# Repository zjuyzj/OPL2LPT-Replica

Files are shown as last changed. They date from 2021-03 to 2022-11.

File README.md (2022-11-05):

# OPL2LPT-Replica

## Introduction
**OPL2LPT-Replica** is a re-designed, open-source simplified version of OPL2LPT circuit board with fewer components under MIT license, acting as a YM3812 FM synthesizer on LPT port, and fully ***Adlib Card*** compatible.

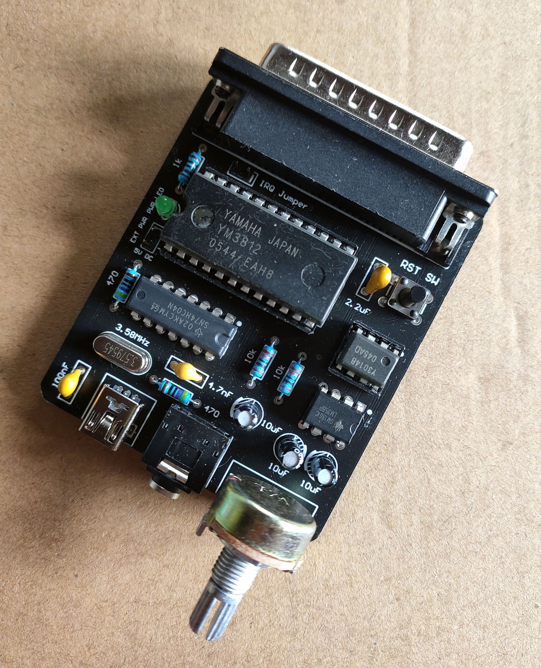
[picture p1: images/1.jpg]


Buy the original version of OPL2LPT and for more info: https://www.serdashop.com/OPL2LPT

## Development & Manufacture
- Please use ***Altium Designer 16*** or above to open or edit the PCB project

- Gerber files and NC drill files are already exported in `gerbers` folder, so that PCB samples can be easily manufactured

   https://www.jlc.com/ is recommended to order PCB samples in China

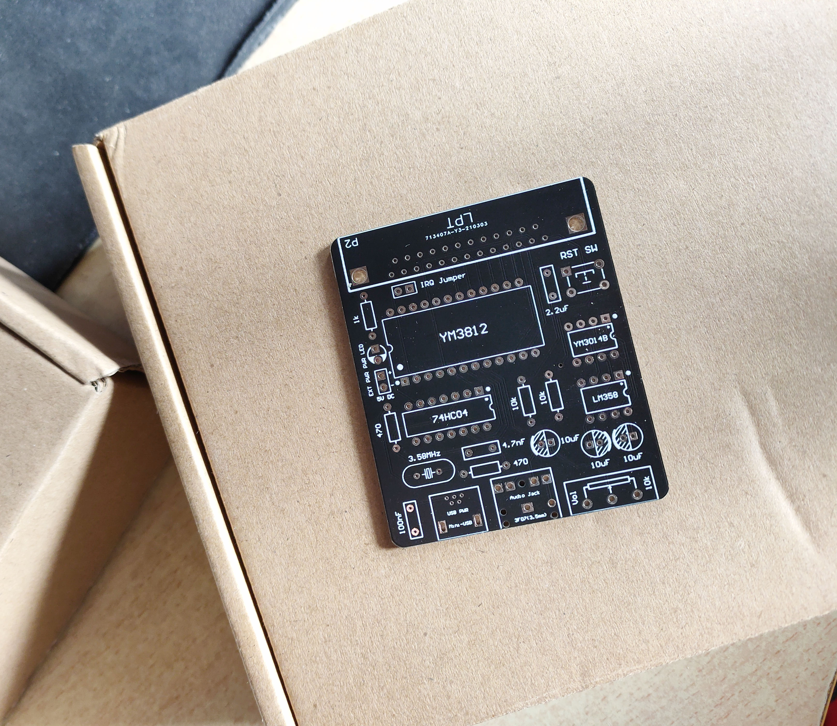
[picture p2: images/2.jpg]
   
## Bill of Material

| Component | Designator | Quantity | Note & Possible Sources |
| --- | --- | --- | --- |
| Leaded 100pF (101) MLCC | C1 | 1 | Mouser 594-K101J15C0GF5UH5 |
| Leaded 100nF (104) MLCC | C2 | 1 | Mouser 594-K104K15X7RF5UL2 |
| Leaded 10uF Pol. Cap. | C3, C5, C6 | 3 | Mouser 667-ECA-1EM100 |
| Leaded 2.2uF (225) MLCC | C4 | 1 | Mouser 81-RDER71H225K2M1H3A |
| Leaded 3mm Green LED | D1 | 1 | Mouser 630-HLMP-Y801-JPP00 |
| 74HC04 CMOS Inverters | IC1 | 1 | Mouser 595-CD74HC04E |
| Yamaha YM3014B DAC | IC2 | 1 | https://www.aliexpress.com/item/32611185781.html, DIP-8 socket is recommended |
| Yamaha YM3812 OPL2 | IC3 | 1 | https://www.aliexpress.com/item/32595976031.html, DIP-24 socket is recommended |
| LM358 Dual OP Amp | IC4 | 1 | Mouser 595-LM358AP |
| Leaded Mini USB Type B Connector | P1 | 1 | Mouser 571-2172034-1 |
| D-Sub 25P R/A Male Connector | P2 | 1 | Mouser 523-L717SDB25P1ACH3R |
| Header 2P 2.54mm | P3, W1 | 2 | Mouser 855-M20-9990246 |
| 3F07 3.5mm Stereo Audio Jack | P4 | 1 | https://www.aliexpress.com/i/32478957056.html |
| 1k 1/4W Resistor | R1, R2, R3 | 3 | Mouser 279-YR1B1K0CC |
| 10k WH148  Potentiometer | R4 | 1 | https://www.aliexpress.com/item/32998649900.html |
| 10k 1/4W Resistor | R5, R6 | 2 | Mouser 279-YR1B10KCC |
| TSW DIP-6\*6\*11 Key | S1 | 1 | https://www.aliexpress.com/item/32725384168.html |
| Crystal HC-49S 3.58MHz | Y1 | 1 | Mouser 449-LFXTAL032257BULK |

## Notes for Assembling & Testing
- 5V DC power is needed, either from Mini-USB port or external power pins

- Try to press **RST SW** to apply a manual reset when YM3812 behaves abnormal

- Detailed parameters for components are noted on the board's silkscreen

- Crystal must be 3.58MHz for accurate pitch of notes

- Using 74LS04 to substitute 74HC04 for the Pierce oscillator is not recommended

  **Note**: If the oscillator doesn't work, replace the two 1k ohms resistors around the 74HC04 IC with higher value resistors such as 4.7k ohms. Fine tuning for 100pF (101) MLCC capacitor around the 74HC04 may be also needed.

- Available open-source drivers for this project:
  - on MS-DOS: https://github.com/pdewacht/adlipt
    
    working fine using either method below
    
    - Using TSR  `adlipt`  for port mapping (with emm386.exe)
    - Using  `adpatch`  to patch part of DOS games
    
  - on Windows 3.1: https://github.com/andreiw/adlib21
## Update Logs
- Version 0.1(beta): First PCB for debugging
- Version 0.2(beta):
  - A smaller re-designed PCB
  - Audio quality improved
- Version 0.3(beta): Fix unconnected GND net for 3.5mm audio jack
- Version 1.0:
  - First version updated on https://github.com/
  - Fix power LED & volume control's problem
  - Use a round PCB corner for easier assembling (with a 3D-Printed case)
  - Pull-up resistors on bus are removed to improve compatibility for some old PCs
  - Use non-SMT Mini-USB port, making it easier to solder by hand
  - Add external 5V-DC power pins
- Version 1.0.1:
  - Add 3D-Printed case (with cover) and knob
  
    Thanks for **@zhblue** for your awesome *.stl models
  
  - Change directory structure for GitHub repo

- Version 1.1.0:
  - Fix clock problem caused by unsuitable resistors and capacitor for Pierce oscillator
  - Add Bill of Material and some images for this README document
  - Export PDF version for schematic and PCB documents

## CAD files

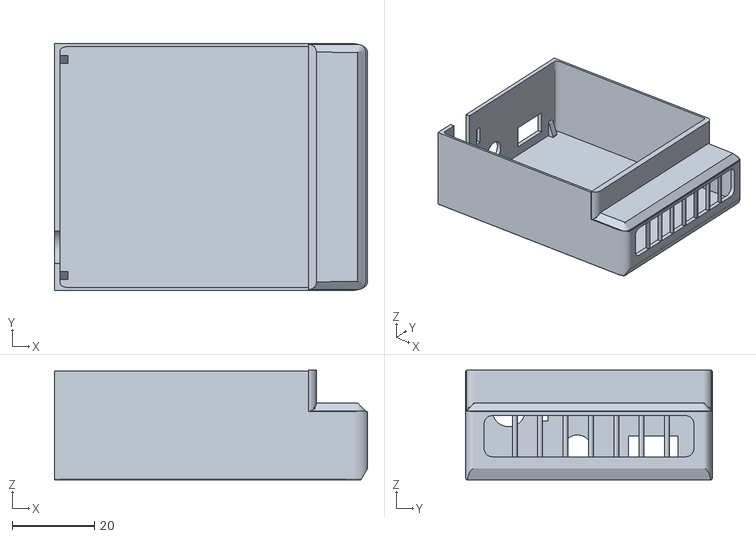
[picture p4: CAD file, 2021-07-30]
models/opl2box.stl
76.1 x 60.0 x 26.7

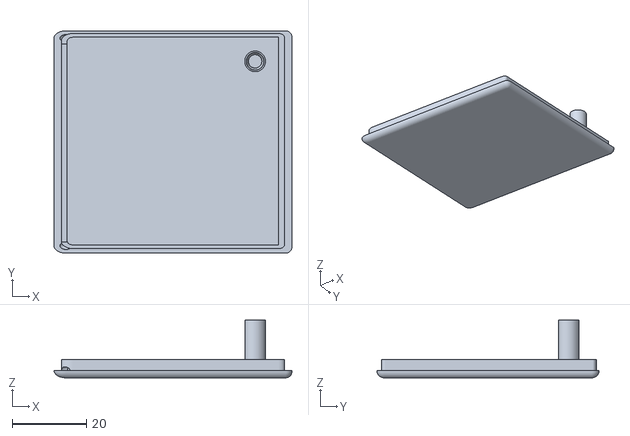
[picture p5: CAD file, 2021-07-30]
models/opl2cover.stl
64.2 x 60.0 x 15.6

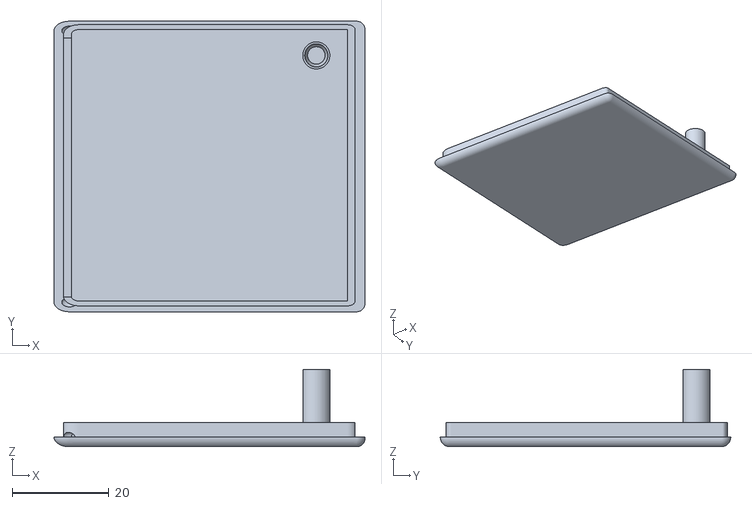
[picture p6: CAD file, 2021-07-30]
models/opl2coverb.stl
64.2 x 60.0 x 16.0

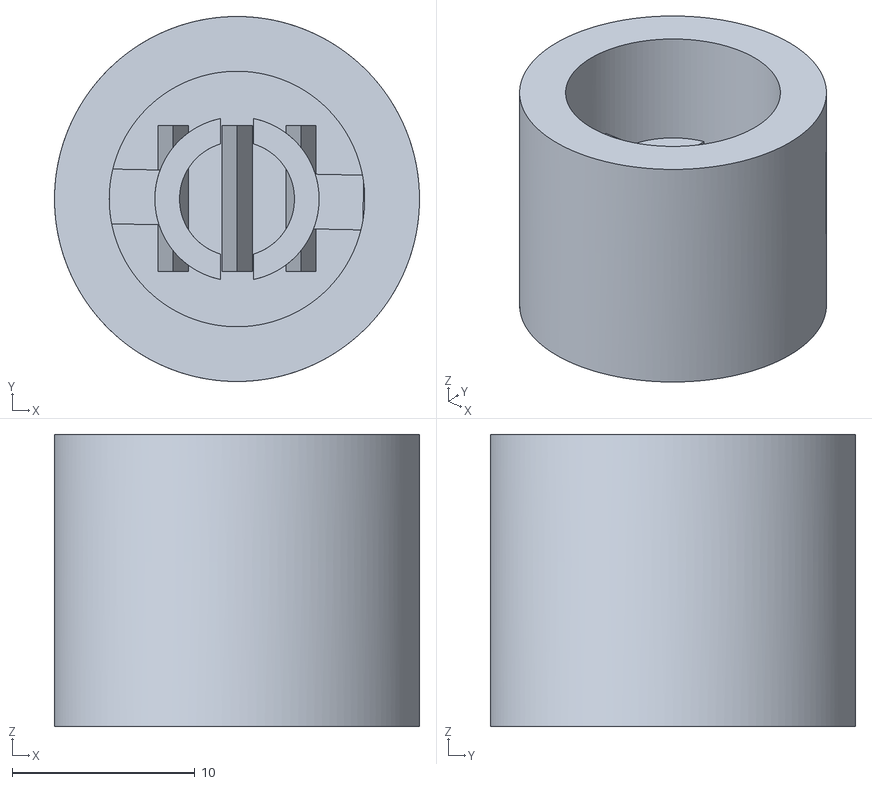
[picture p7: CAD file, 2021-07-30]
models/opl2knob.stl
20.0 x 20.0 x 16.0

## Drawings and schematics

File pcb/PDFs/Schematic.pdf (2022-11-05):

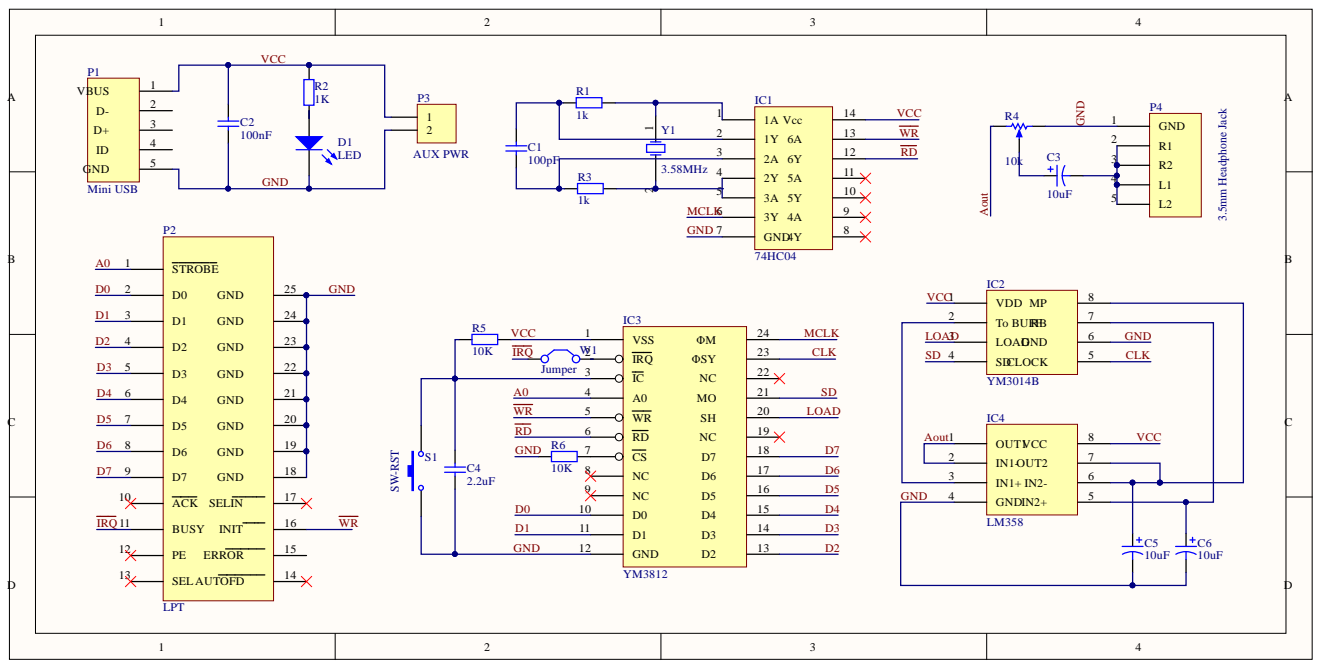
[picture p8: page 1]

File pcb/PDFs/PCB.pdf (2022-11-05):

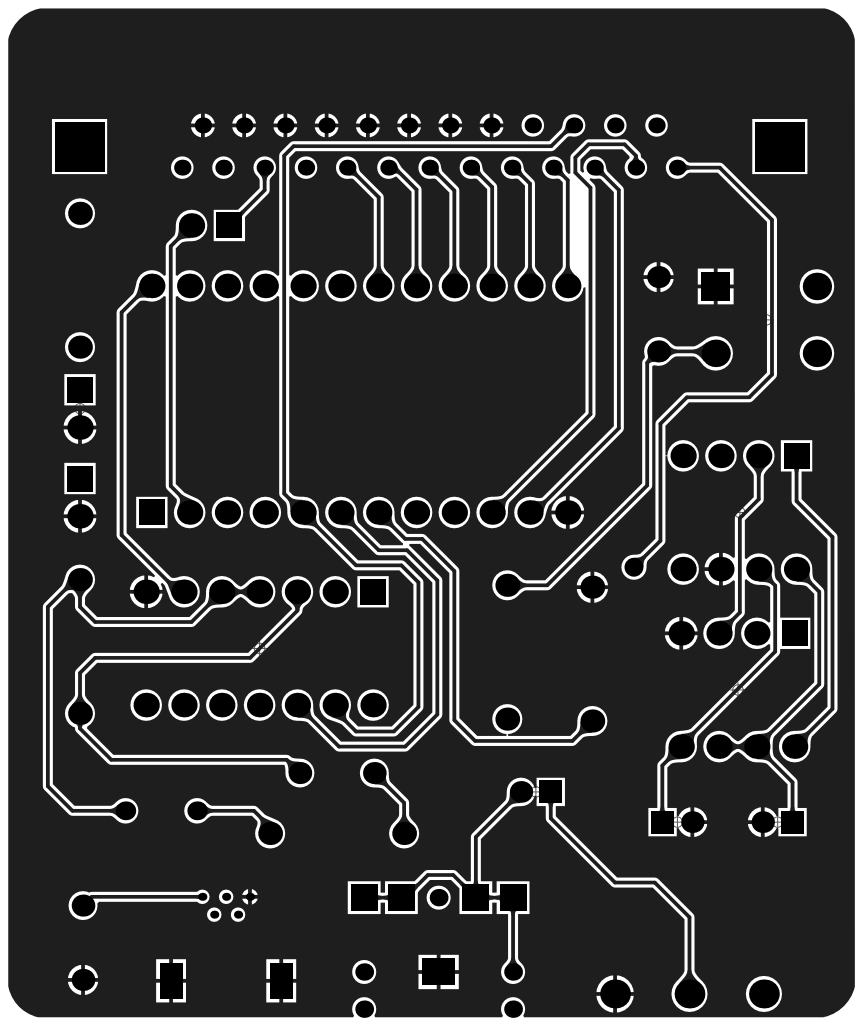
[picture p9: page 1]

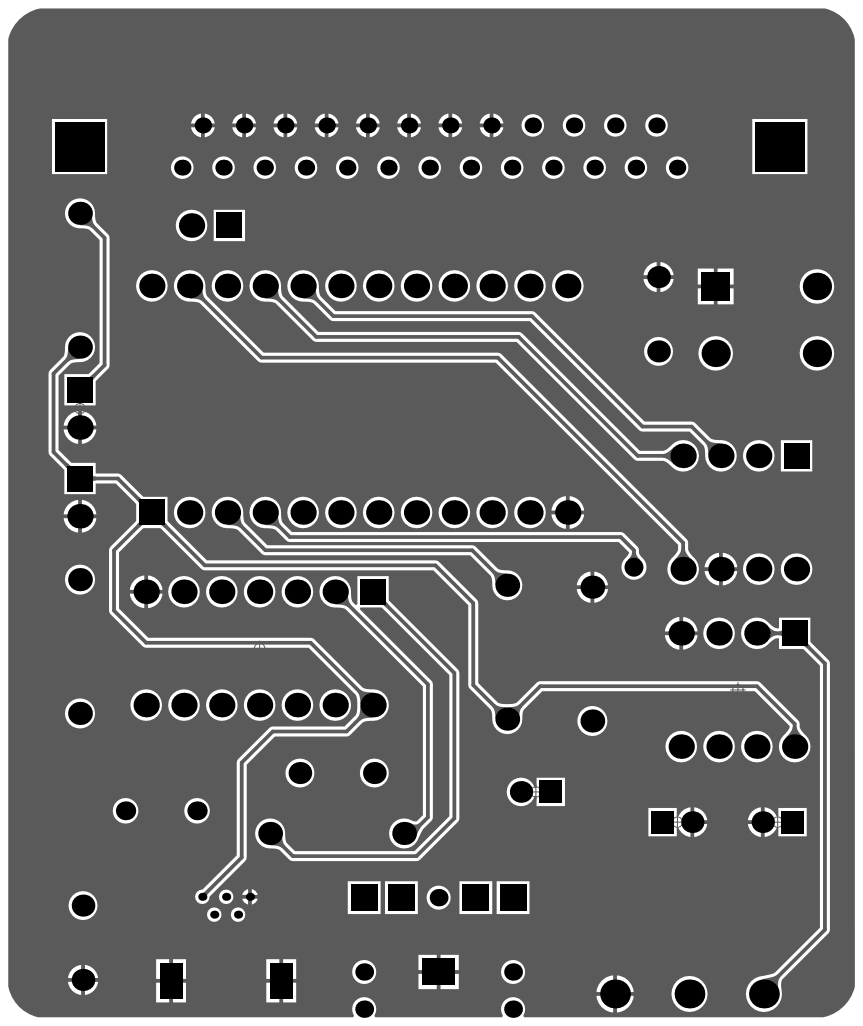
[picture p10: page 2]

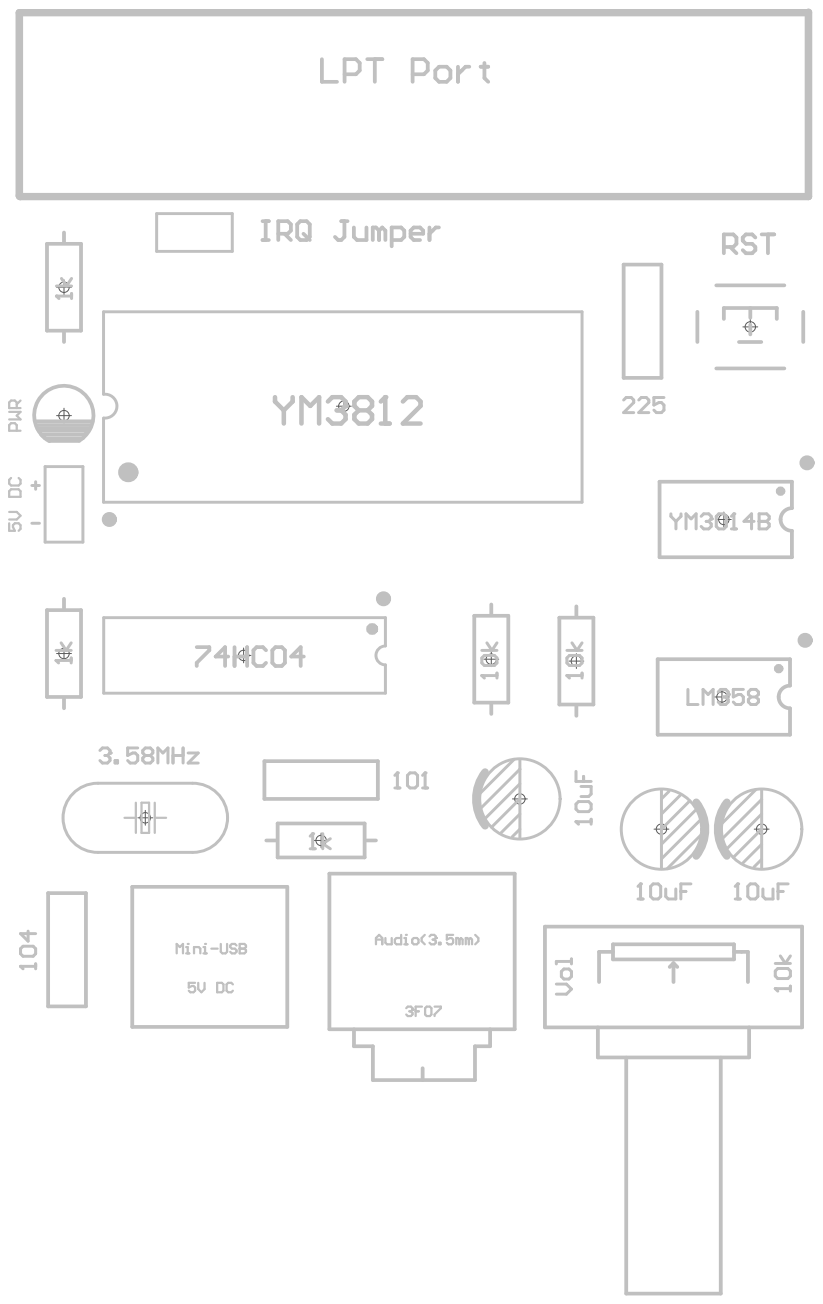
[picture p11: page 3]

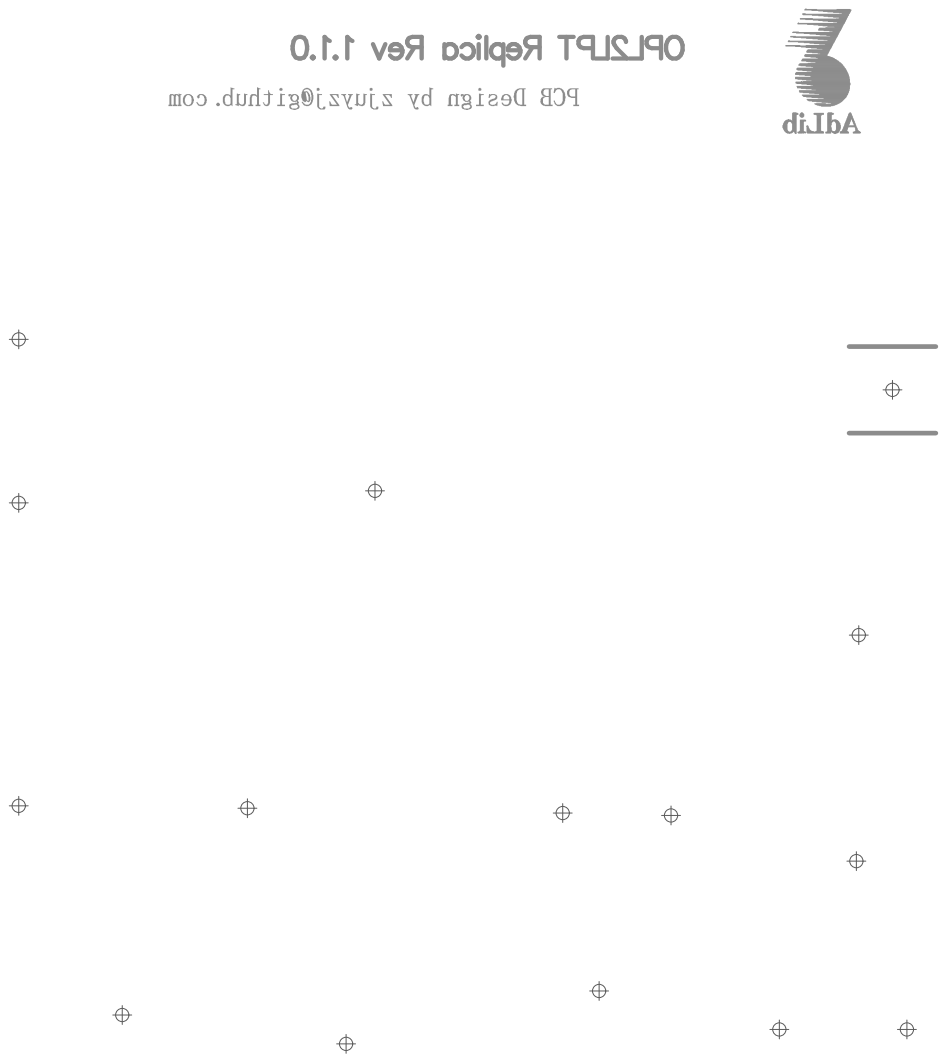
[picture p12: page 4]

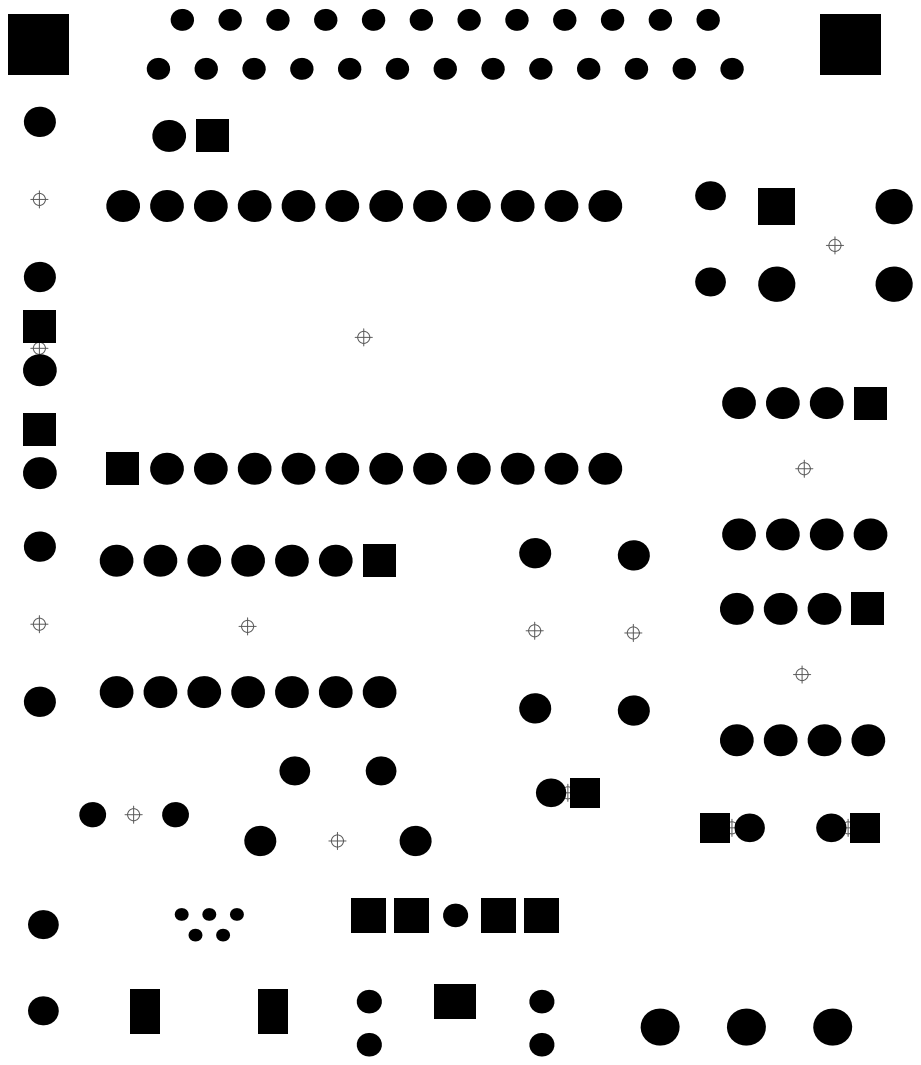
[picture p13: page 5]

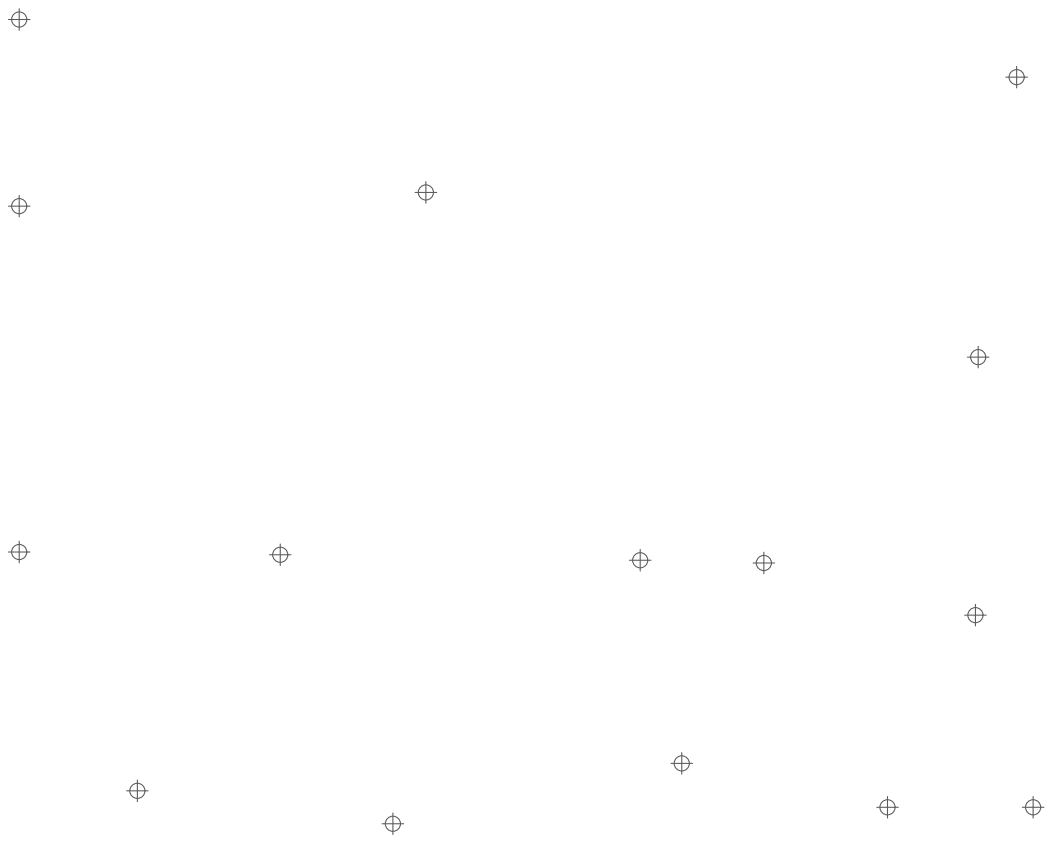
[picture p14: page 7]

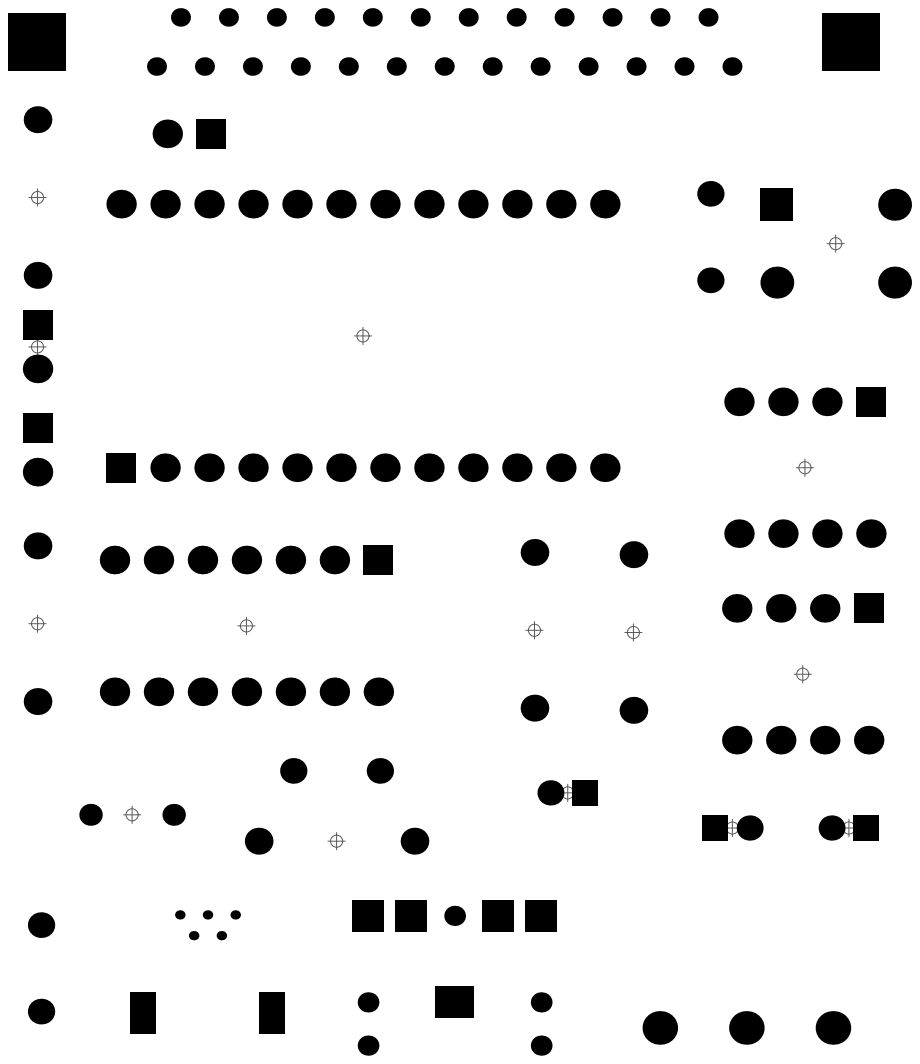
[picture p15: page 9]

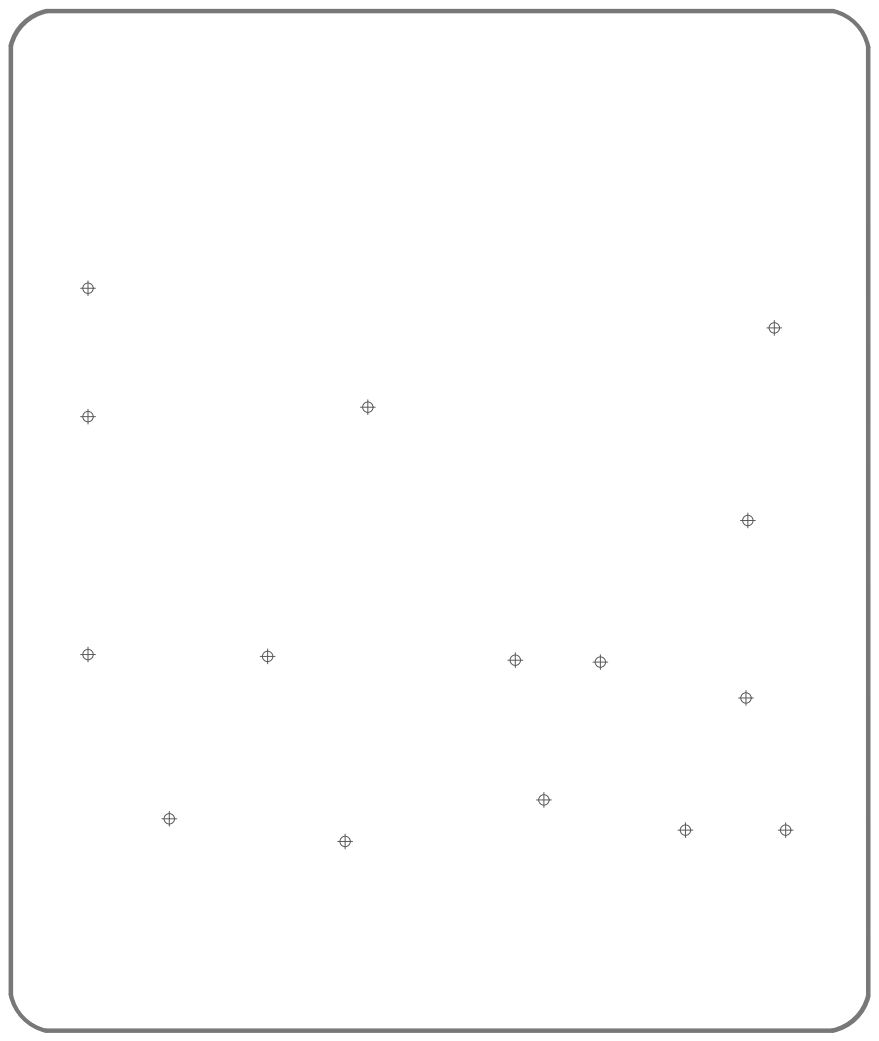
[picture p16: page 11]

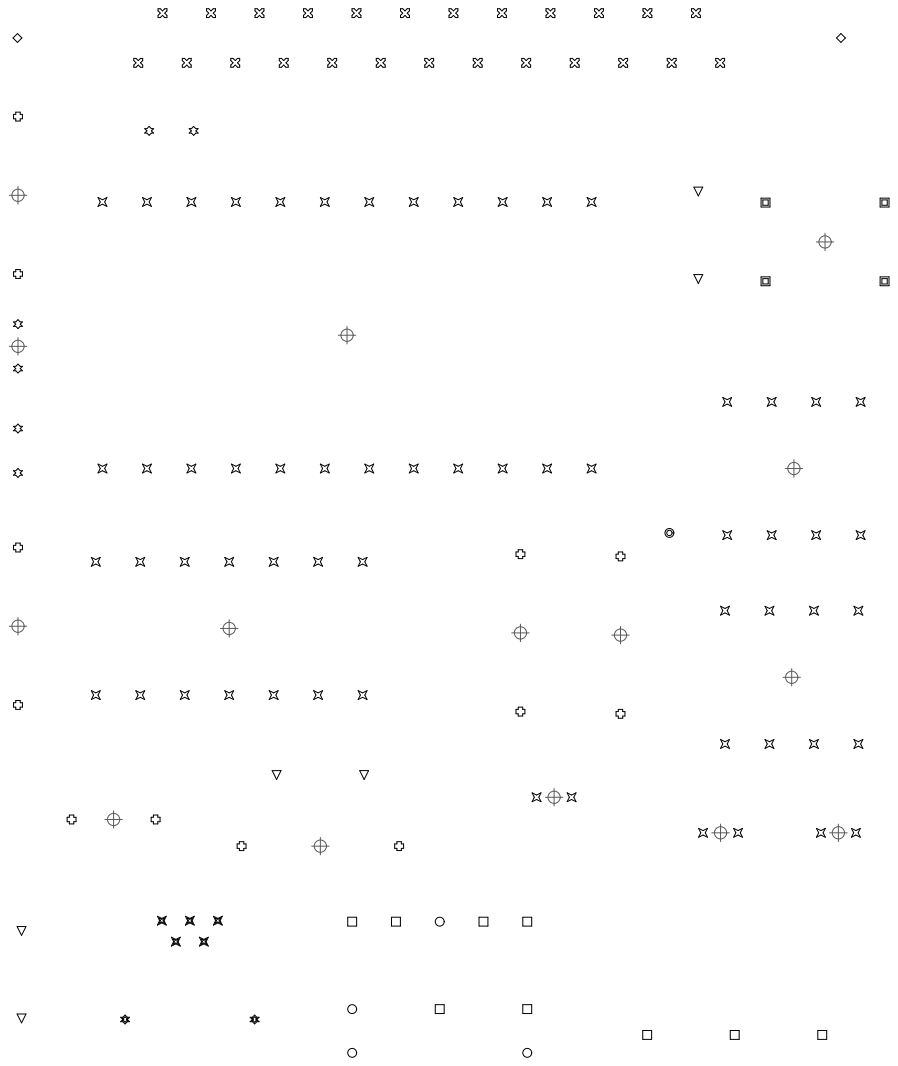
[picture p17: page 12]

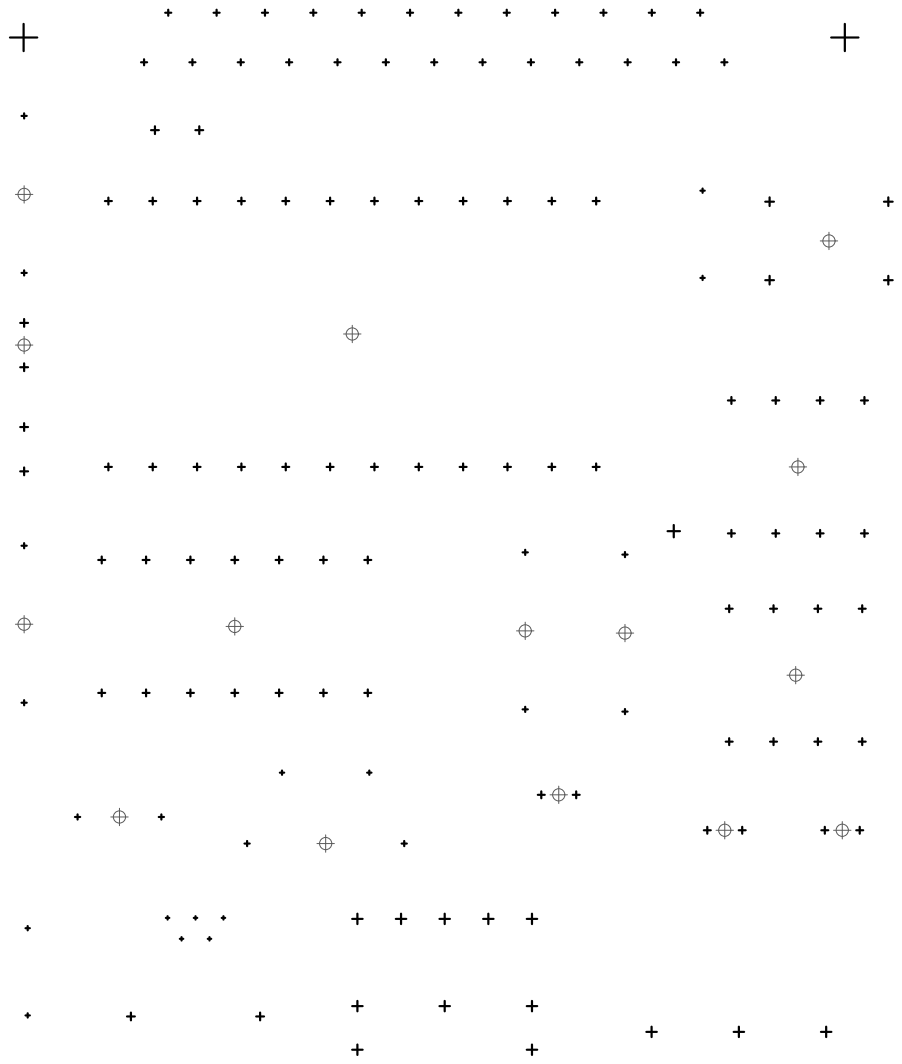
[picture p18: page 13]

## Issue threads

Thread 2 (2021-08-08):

74HC04  vs SN7404n notice

zhblue, 2021-08-08:
an second hand IC maked sn7404n england works fine with 470 ohm resister
but a brandly new IC maked 74HC04 from JLC market need a 4.7k ohm resister to work with.
i have no idea about why , just post here for people who might need it.

zhblue, 2021-08-18:
the extra 470 ohm resister can be used parallelly on the outer two pin of volume control, make volume adjust more smooth.

AidenShaw2020, 2022-01-14:
I had same issue, that me get almost crazy, but resolution is pretty quite simple :)
Only what you need is change oscilator circuit from this:
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
, to this:
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

After that, you get perfectly stable frequency +/-1Hz.

dekkit, 2022-03-13:
Interesting i had a batch of SN7404n (ordered 5) ..4x worked with 470R.

..but  1x pcb needed both 470 replaced with a  4.7k.

I suspect anything above 1k will work more consistently.

Note (new builders):
- if building the circuit the first time - becareful and pay attention to the dots and chip orientation (as labels written on the pcb arent necessarily orientated the correct way)

badass-boss, 2023-05-16:
These values must still be just downright incorrect. This card doesn't work right at all using all original mouser parts linked in the BOM. 1K resistors paired with a 100pf cap generate a TON of random noise and loud glitches and the FM music gets all corrupted at all times. When changing resistors to a higher value, the issue is fixed and I think this card works best with 4.7k resistors. What are these resistors even supposed to achieve and what is the configuration of the original Adlib card?

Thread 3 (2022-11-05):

Bill of materials (BOM)

mgoulartBR, 2022-11-05:
Greetings,

Is it possible to share a file listing de needed materials (TXT file) in order to build this PCB?
I tried to search it through the directories but I didn't find it.

Thanks!

zjuyzj, 2022-11-05:
Thanks for your feedback! A Bill of Materials is appended to the README.md as a table in Markdown now with possible sources for all electronic parts (most of which from Mouser, fewer from AliExpress). PDF version of schematic and PCB are also exported for PCB building and debugging.

mgoulartBR, 2022-11-06:
Thanks a lot!!!

Closed 2022-11-06.

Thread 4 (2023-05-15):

Audio is malfunctioning

badass-boss, 2023-05-15:
I assembled this OPL2LPT replica using all linked parts from mouser and YM3812 from the linked aliexpress seller. I socketed all chips. Sometimes there is a very strong humming noise coming out of the speakers and other times FM music playback in games gets all desynced and broken. This is not a very good start... I used 1k resistors and a 100pf cap on the crystal circuitry

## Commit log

2021-03-03 Add first stable version of PCB(v1.0) and manufacture files.
    [OPL2LPT Replica.PrjPcb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]
2021-07-30 add 3d print model
    [opl2box.stl, opl2cover.stl, opl2coverb.stl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]
2021-07-30 Update version v1.0.1 with *.stl models.
    [OPL2LPT Replica.PrjPcb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]
2022-11-05 Update version 1.1.0, fix unstable 74HC04 problem and add BOM and images to README.
    [Schematic.SchDoc, Schlib.SchLib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]
